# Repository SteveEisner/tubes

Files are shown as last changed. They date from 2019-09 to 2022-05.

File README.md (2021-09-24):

# tubes
These portable LED light poles make pretty lights for a dance party - and better yet:

They're **portable**! Convenient tripod bases keep them standing at attention, and a 10Ah USB battery (like the one you charge your phone with) will power them for about 8 hours.

They're **versatile**! You can deploy them in a [wide open space at Burning Man](https://youtu.be/UtXL0ScNUoE), in a [private event space](https://youtu.be/B6OBde7zRN4), or right next to each other [in your living room](https://youtu.be/UmiRBCOAMBg).  (Click into these links for videos of them in action.)

They're **coordinated**! If you put them next to each other, they sync using near-field radio. And they'll even daisy-chain, meaning the furthest ones can be really far apart as long as there are some in the middle to relay the signal.

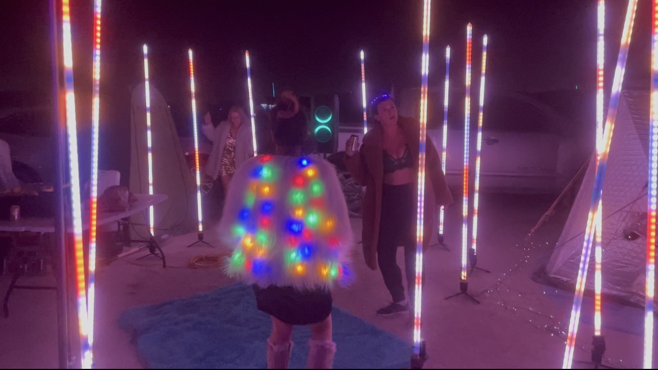
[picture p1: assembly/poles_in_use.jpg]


They're **sturdy**! I built 20 of them and deployed them at parties in all kinds of weather, from hot & dusty windstorms to torrential rain. They've been tossed in a truck, carried around as totems, knocked or blown over, and almost all of 'em are still working.  Just don't let people use them like light sabers (lesson learned.)

They're also **in progress** with lots of things that could be improved.  But for now:

* they play patterns from an expanding set of "genetically-driven" combinations
* they stay in sync or deliberately drift from each other in pleasing ways
* they operate internally at a certain BPM - allowing them to sync to music

### How do they work?

Each light tube is running custom software on a Teensy LC (Arduino-compatible) microcontroller. The software is running a generative light program that has a simple "DNA" specifying its pattern, color, effects overlay, offset, and so on.

The patterns run on a clock that's synced to a specific BPM and counts out the 4/4 rhythm of most dance music, so they morph and change on individual beats, measures, and phrases. After several beat phrases pass, a pole's DNA is mutated a little, which can cause it to change color, or adopt a new pattern, etc.

An on-board NRF radio lets a light pole broadcast its DNA and clock timer; when others hear the signal, they can choose to follow along by updating their own pattern DNA to match it. The method of coordination is pretty simple right now: each pole has an 8-bit ID, and lower-ID poles obey higher-ID poles.

If they're all close enough, they'll soon start doing the same thing as a group and keeping their clock timers in sync. In case they're not close enough, poles also re-broadcast all the signals they receive and obey. This lets them pass along a signal through the group until all of them have found it.

Some randomness and chaos is intentional. Radio isn't 100% reliable, so they sometimes fall out of contact and then re-connect. And in some cases, the poles will deliberately offset their own clock a bit so that they are clearly doing the same thing but not exactly at the same time. Each tube is actually running several copies of the software and smoothly "cross-fading" between them, to avoid any jarring transitions.

### Want your own?

They're not for sale, but check out the build instructions in [this directory](assembly), complete with a parts list & assembly instructions. I'd love it if you build your own!

### Credits

The form factor was inspired by [Mark Lottor's Hexatron](http://www.3waylabs.com/projects/hex/). The color schemes were inspired by [the work of Christopher Schardt](https://americanart.si.edu/exhibitions/burning-man/online/christopher-schardt) and many were found on [cpt-city](http://soliton.vm.bytemark.co.uk/pub/cpt-city/).  The code was written using [FastLED](http://fastled.io/) and most patterns are evolved versions of FastLED examples.  It's based on [Chuck Sommerville's led-swarm](https://github.com/chucks13/LED-swarm), and still follows its [theory](https://github.com/chucks13/LED-swarm/blob/master/theory.txt) for radio connection. I used [Paul Stoffregen's WS2812Serial](https://github.com/PaulStoffregen/WS2812Serial) for smooth animation, and of course [his Teensy CPU](https://www.pjrc.com/teensy/teensyLC.html) made the whole thing possible. Standing on the shoulders of these giants let me create these in about a month, in time to debut at Burning Man 2019 and appear at many parties since!

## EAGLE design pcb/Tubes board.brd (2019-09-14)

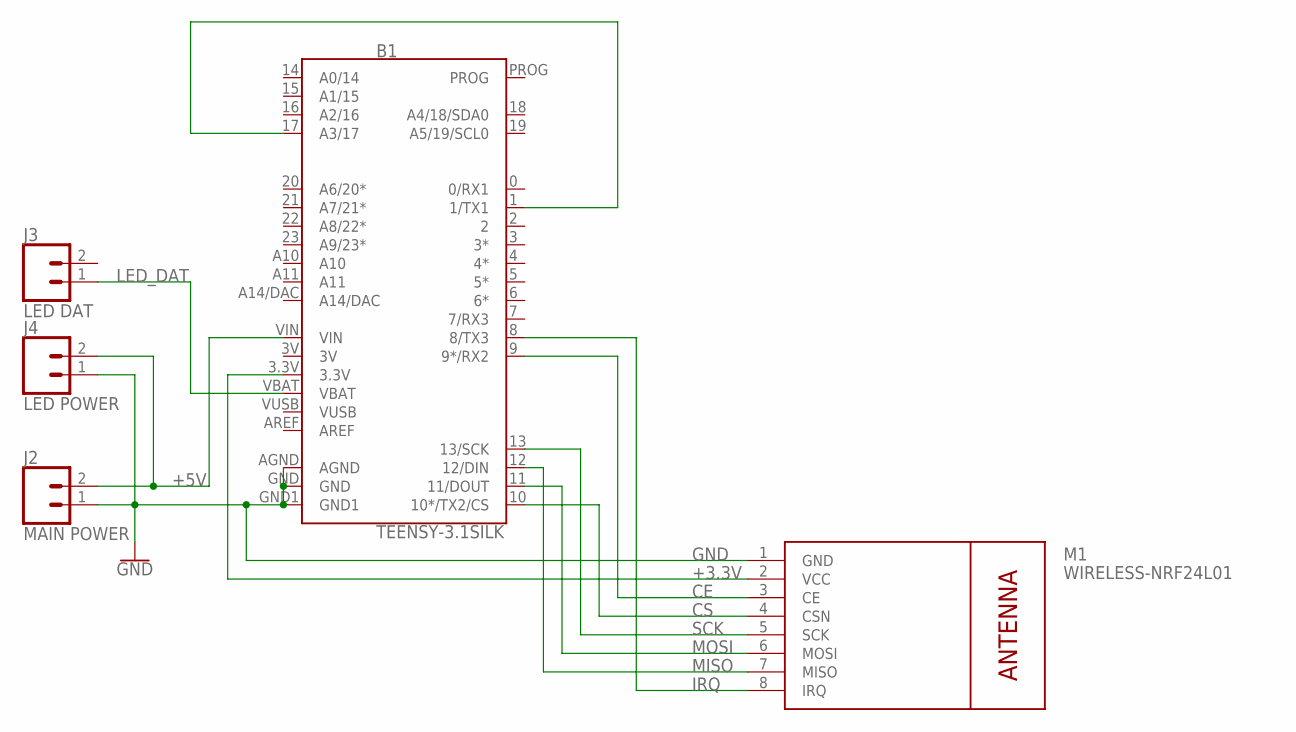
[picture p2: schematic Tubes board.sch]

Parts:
B1: TEENSY-3.1SILK; TEENSY-3.1
J2: MAIN POWER; SCREWTERMINAL-5MM-2
J3: LED DAT; SCREWTERMINAL-5MM-2
J4: LED POWER; SCREWTERMINAL-5MM-2
M1: WIRELESS-NRF24L01

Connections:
3V: B1.3V
+3.3V: B1.3.3V, M1.2 (VCC)
+5V: B1.VIN, J2.2, J4.2
CE: B1.9 (9*/RX2), M1.3 (CE)
CS: B1.10 (10*/TX2/CS), M1.4 (CSN)
DAT: B1.1 (1/TX1), B1.17 (A3/17)
GND: B1.AGND, B1.GND, B1.GND1, J2.1, J4.1, M1.1 (GND)
IRQ: B1.8 (8/TX3), M1.8 (IRQ)
LED_DAT: B1.VBAT, J3.1
MISO: B1.12 (12/DIN), M1.7 (MISO)
MOSI: B1.11 (11/DOUT), M1.6 (MOSI)
SCK: B1.13 (13/SCK), M1.5 (SCK)
VUSB: B1.VUSB

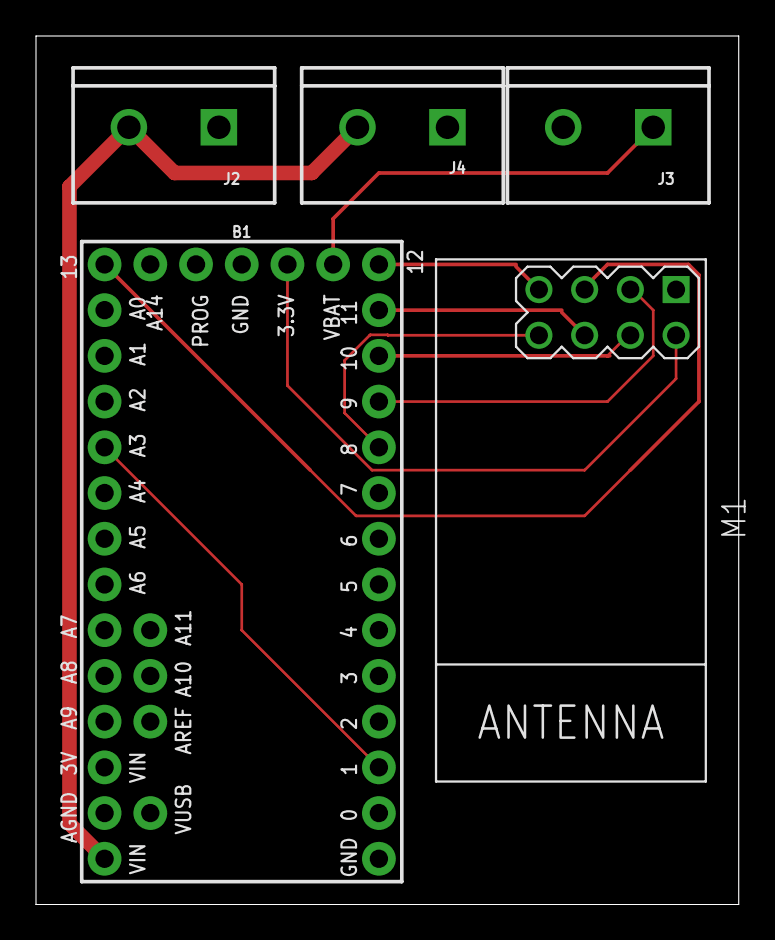
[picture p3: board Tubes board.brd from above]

Board: 2 copper layers, 39.0 x 48.2 mm, 5 parts (0 on the bottom side), 11 nets.

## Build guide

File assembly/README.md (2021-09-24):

# Assembly instructions
How to build your own light tubes.

Quick list of the parts involved:

* A custom PCB (printing instructions & parts are included below.)
* A [specimen cup / paint sample cup](https://www.amazon.com/gp/product/B07RYRF67N) that serves as the housing for the electronics
* A [camera tripod](https://www.amazon.com/gp/product/B072JW7PWX) that acts as the legs
* A [tripod adapter plate](https://www.amazon.com/gp/product/B00H6P57O6), used to strengthen the cup bottom.
* A [flanged nut](https://www.amazon.com/gp/product/B07MJVXWPR) that holds the base together
* The LED light tube itself
* A [shower bar flange](https://www.amazon.com/gp/product/B07K6D7D4F) that holds the light tube in place
* 3 bolts/nut pairs that mount the flange on the top of the cup
* A screw and washer that holds the LED bar against the cup top
* [Mounting foam](https://www.amazon.com/gp/product/B07NYR181P) to secure the PCB
* (Optional) Some [weighted bases](https://www.amazon.com/gp/product/B00PCS196E) that you can slip the tubes into

## The electronics

Eagle files for printing your own PCB are in the [pcb](../pcb) directory.  I used [jlcpcb.com](jlcpcb.com) to print them - fast and cheap! It's incredible that you can have PCBs from Hong Kong at our doorstep within a few days.

The tubes are "meteor lights" like [these ones](https://www.aliexpress.com/item/32678345729.html) but use the frosted plastic like [these ones](https://www.aliexpress.com/item/32977080489.html ) (note that this link is 12V LEDs, don't get those!). Ray Wu's store is universally trusted by LED artists and they do custom orders - they made me some **frosted 2m 5V 30/m SK6812s**. The great thing about these lights is that they're double-sided, for much better 360-degree view of the lights. Each "LED" in the strip is actually a front-and-back pair.

If you want to change the LEDs, for instance to use a different chipset or more LEDS per meter, it'll mostly scale to any size, but you'll need to make small updates the source. You also risk increasing the power consumption.

The code is written for a [Teensy LC](https://www.pjrc.com/teensy/teensyLC.html) microprocessor. It's a cheap, powerful CPU with some nice features for LED applications. You'll need the [Arduino](https://www.arduino.cc/) development environment to flash the code, and I recommend [VSCode](https://code.visualstudio.com/) + [PlatformIO](https://platformio.org/) for editing.

The PCB also has holes ready to accept an NRF radio. I used the ones [without an antenna](https://www.amazon.com/gp/product/B00O9O868G) in each pole. I suppose it could be redesigned around [having an antenna](https://www.amazon.com/gp/product/B07PBBC4H9) although that'll change the form factor a lot. I did use an antenna for the hand-held controller I built - see pics at end.

Finally, each PCB uses 3 [screw terminals](https://www.amazon.com/gp/product/B01MT4LC0F/) for 5v power and data connections.

There are a few improvements I'll make for future versions:

* For USB power, I cut up the USB cords that came free with the batteries I bought. But they're a little short & hard to work with when assembling the base. I'd recommend using longer ones (up to a foot long versus these 4" ones.)
* Oops. I'm going to have to fix the fact that I missed a useful/necessary wire from pin 1 to pin 17 of the Teensy. If you use these boards **you'll need to add a jumper wire** like I did, sorry! :)

## The base

The finished base will look like this:
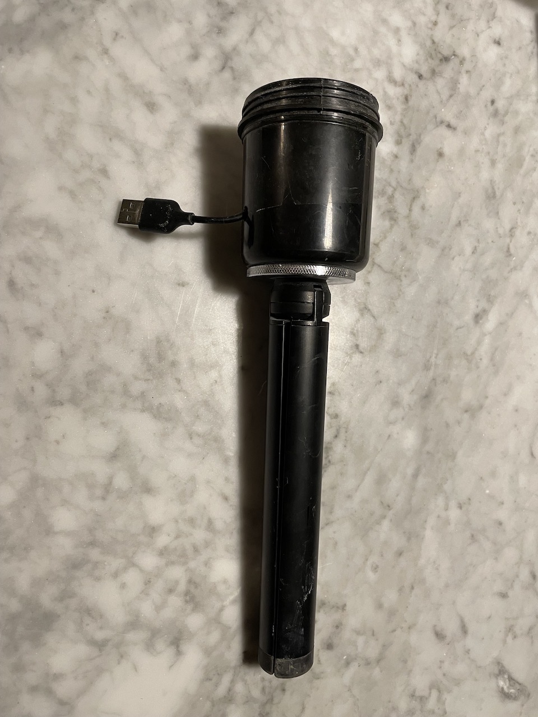
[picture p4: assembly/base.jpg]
base

The tripod is screwed into an adapter plate that provides some stability. That adapter is screwed through a hole in the bottom of the cup, and locked in with a nut on the inside.
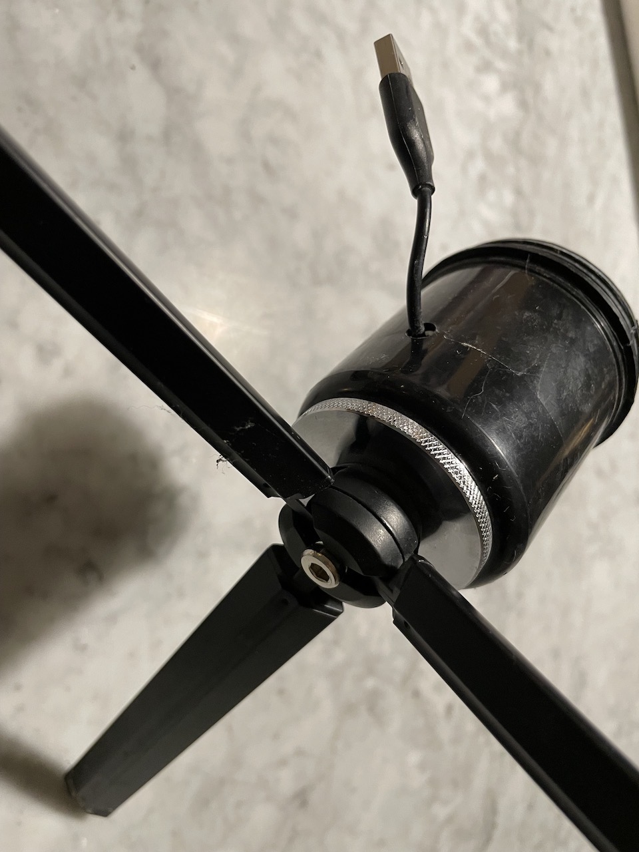
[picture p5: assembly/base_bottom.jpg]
base bottom


Looking down into the cup, you can see the flanged nut that holds it together:
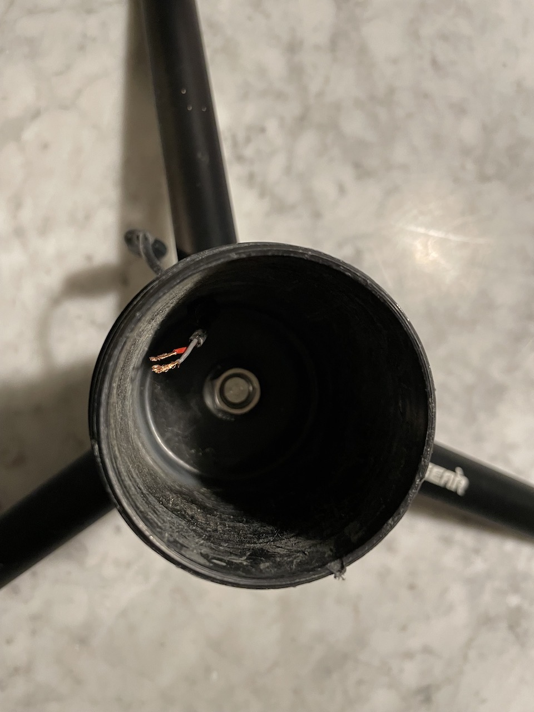
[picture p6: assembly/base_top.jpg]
base from top


Some things I learned while building the base:

* The plastic base of the cup isn't strong enough by itself. It needs to sit on the metal adapter or else the cup will flex/deform and the whole thing will fall over.
* There are multiple kinds of tripods out there. Make sure to get the one that have the updated center screw because the older ones get loose/floppy very quickly.  You'll see mention of this in the seller's notes - they talk about a "version 2" or "updated sturdy screw".  [The Pergear](https://www.amazon.com/dp/B072JW7PWX/ref=emc_b_5_t) tripods I used have the updated bolt, [these Zeadio](https://www.amazon.com/Zeadio-Desktop-Tabletop-Stabilizer-Cameras/dp/B07GST1C2Z) ones don't.

## The tube
The finished tube will look like this:
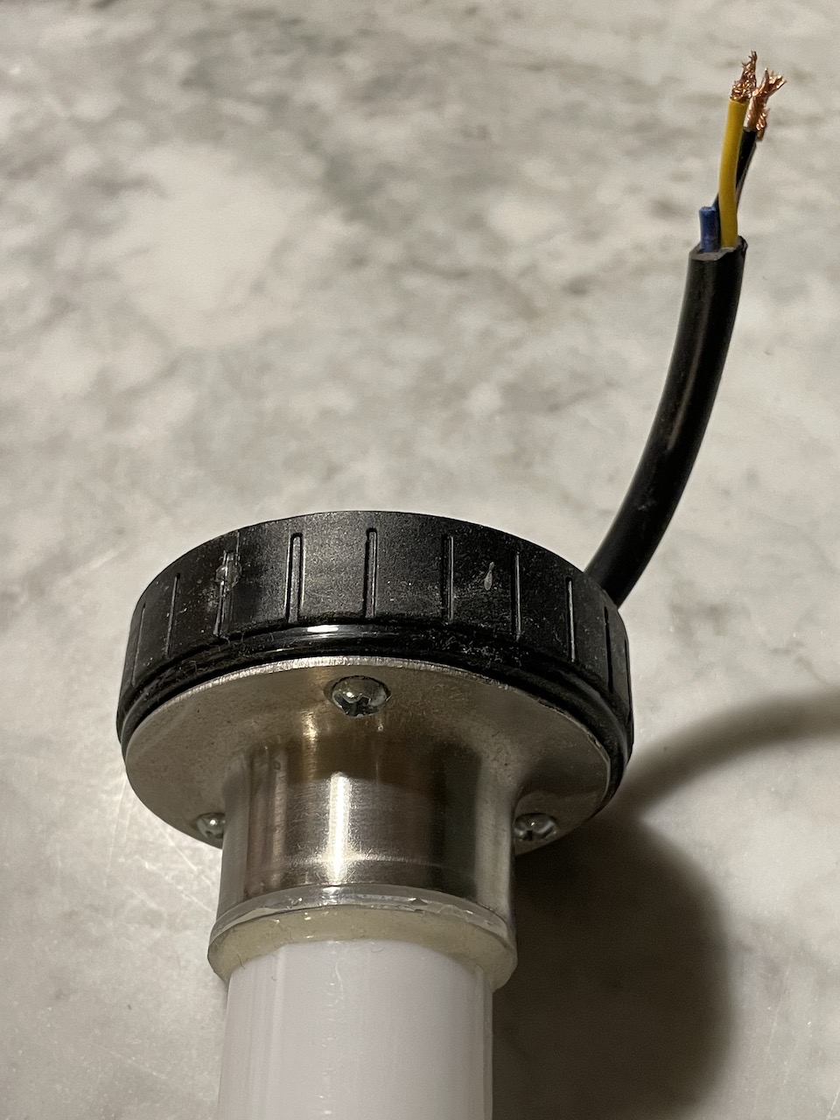
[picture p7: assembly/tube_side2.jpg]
tube from side

They're mounted on the top of the cup, with a flange to hold them in place.

The light tubes are pretty bare when they arrive - no easy mechanism for mounting. I found that I could give them strength by screwing into them from the bottom, but that required a special mounting plate:
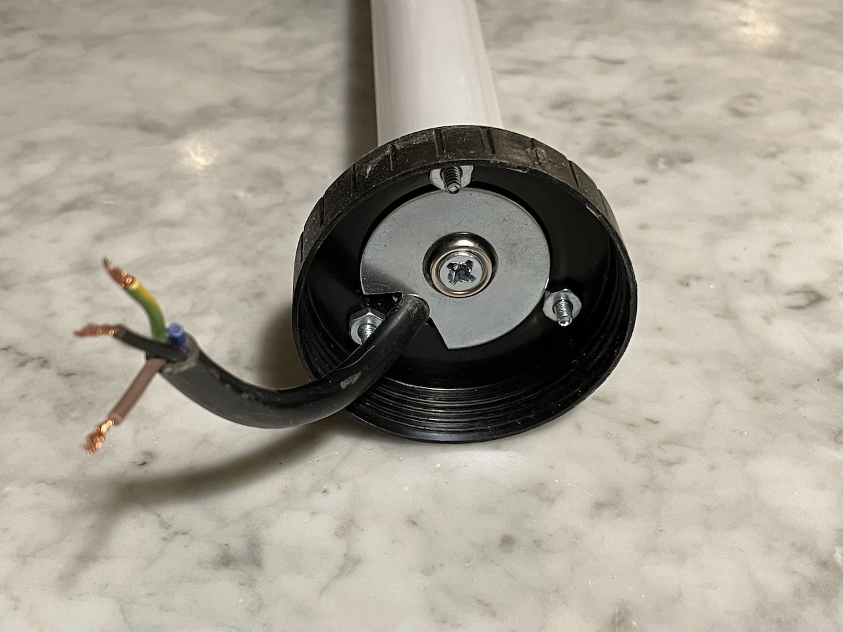
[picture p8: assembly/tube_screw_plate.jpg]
tube plate view


The plate is just a wide washer. I used a drill press to make a hole for the LED strip connector wires, then opened it up a bit with a band saw. You might not need to do that, but it made it easier to get the wires through.

A screw goes up through the washer into the plastic of the tube. It wouldn't be strong enough by itself (the plastic would crack with any pressure on the tube) so the flange on the other side holds it in place. Then the flange can be screwed in from the other side.

Some advice:
* Pre-drill the holes in the cup top. Each will have four holes: three small ones for the flange's screws and one large center one. The center one has to be pretty big to accommodate the wires - I mader mine about an inch wide. The washer/screw combo is clamping the tube to the cup top, so make sure there's enough of the top left to give it strength.
* Also pre-drill a hole into the tube, to prevent the plastic from cracking under strain when you screw into it.
* Between the width of the flat washer and the nuts that hold the flange on, it's pretty tight for space. In my case the nuts just barely fit around the outside of the washer, so screw those 3 in first, and then do the center washer. As a side effect this also keeps the nuts from coming loose, because the washer is keeping them from turning.

## The guts
With the tube and base ready, it's time to fill up the specimen cup. With a PCB!

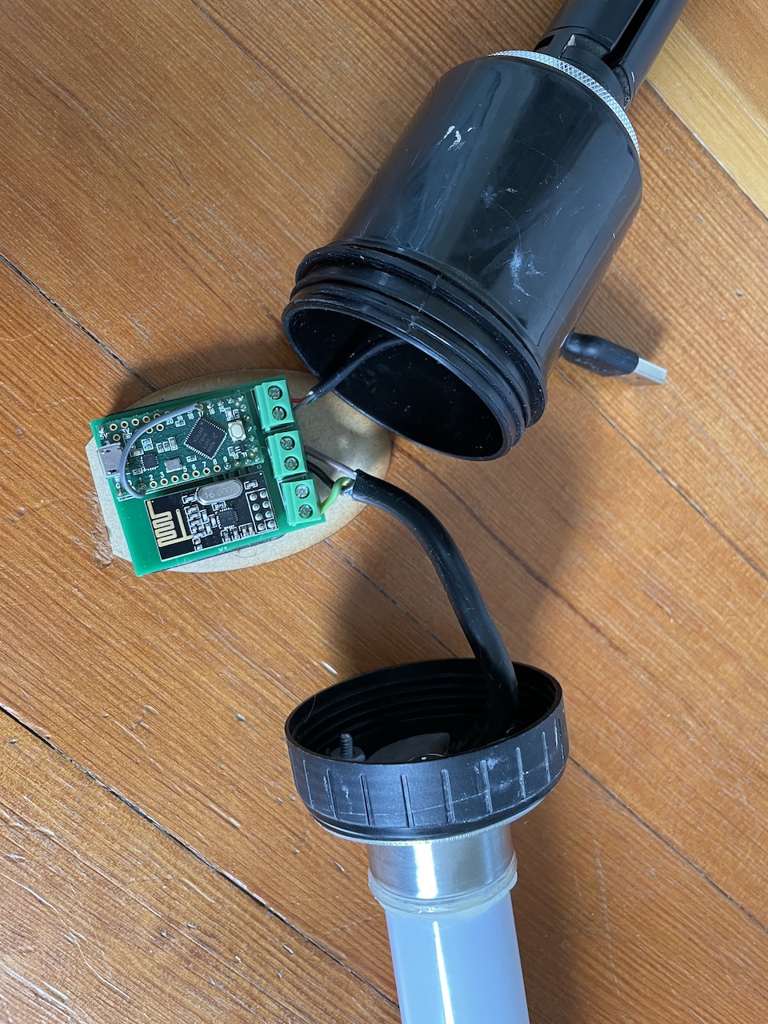
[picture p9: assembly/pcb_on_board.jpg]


My friend laser cut me some elliptical wooden discs to mount the PCBs on:

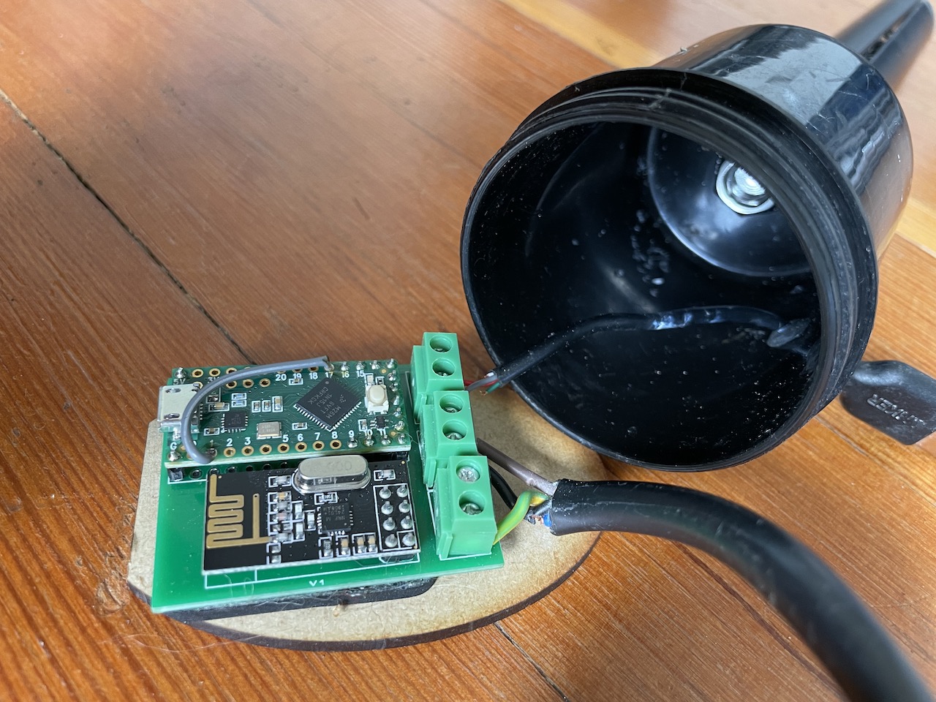
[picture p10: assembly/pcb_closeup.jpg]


They provide some stability to keep the PCB from bouncing around inside the cup. But you could use anything to mount them. The important thing is to not let the PCBs touch the other metal in the cup - the nut on the bottom or the washer & fasteners on the top.

I used double-sided mounting foam to stick the PCB to the wood.  If you don't want to laser cut the wood, maybe you can use the same stuff to make some non-conductive circles and cover the nut and the washer instead.

Lessons learned:

* The cup top screws on to the cup bottom. When you do this, you're going to twist up the wires that are attached to the PCB unless it can freely rotate inside the cup, and even then they'll probably have some twist on them. Make sure the ends of the wires are long enough that they don't get pulled out of the screw terminals.
* The screw top of the cup feels like a weak point, since the top pops off with a little force. Turns out this is a feature not a bug!  By giving the whole thing a bit of a deliberate weak point, it takes pressure off the -true- weak point, which is the glue they used to make the tubes. If you hold everything else solidly together, the tubes themselves will break when a pole falls over!

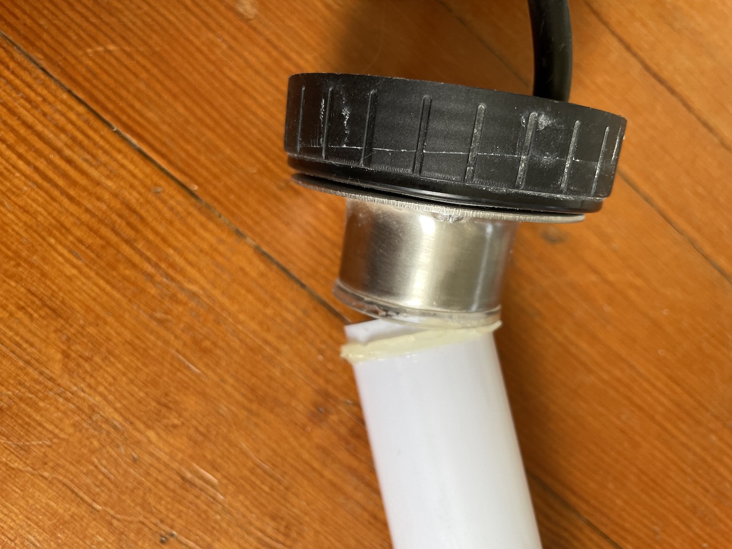
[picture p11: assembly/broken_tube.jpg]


## The controller (optional)

Okay, this part is totally awesome/embarassing.

The day before leaving for Burning Man, I made myself a new toy.

The tubes normally work really well and sync automatically. But their range is limited by the fact that the NRF chips don't have a very big antenna. Occasionally they'll even be right next to each other and still not see each other, in which case one or two might drift apart from the rest.

To achieve perfect coordination, I built a hand-held controller which has the same PCB, but this time I used an [NRF with a big antenna](https://www.amazon.com/gp/product/B07PBBC4H9). It has a special ID that the tubes will always obey, so it acts as a dictator with special powers. It gets them all in sync even if they're 50+ feet apart. And while I was building it, I added some UI to force them to change patterns, colors, and tempo.

It's super useful and also the ugliest thing I've ever built.

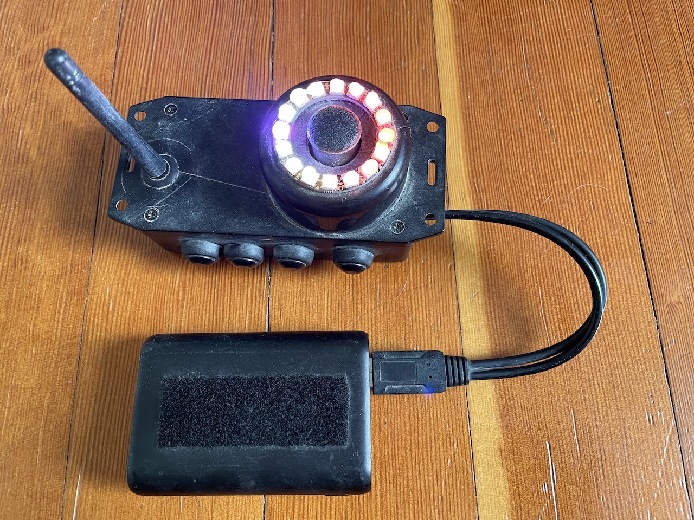
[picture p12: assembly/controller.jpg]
contorller


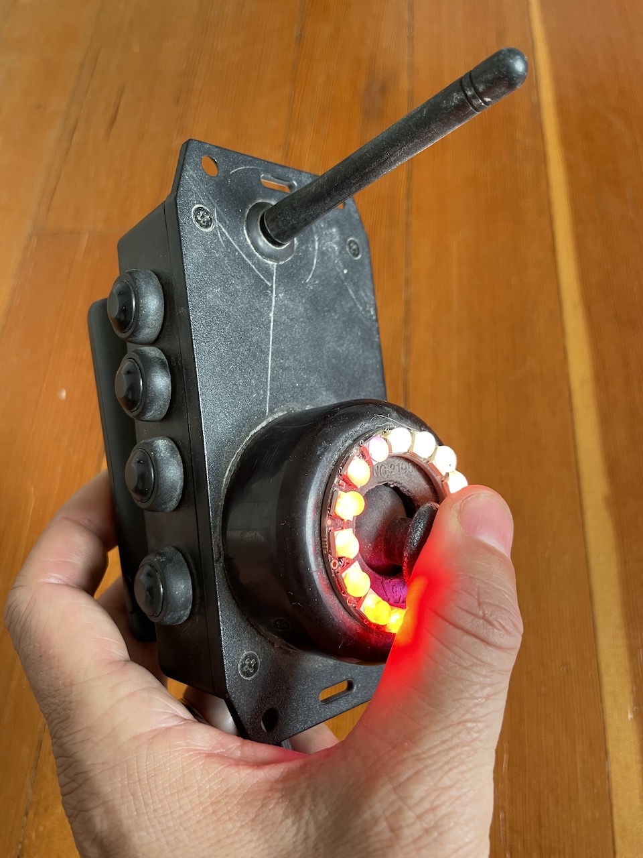
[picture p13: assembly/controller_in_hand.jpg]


I'm not going to do full build instructions for this, but maybe it'll inspire you to make your own. I used parts I had on hand:

* A project box for the body
* The same PCB, now with greater range & a special version of the software
* A rotational joystick like on an Xbox/PS controller
* The bottom of one of the cups as a base for the joystick
* Four pushbuttons
* A 16-LED ring around the joystick
* Hot glue(!) to make diffusers for the LEDs, otherwise they're painfully bright
* Velcro to securely attach a battery under this very ergonomic device
* A [Y-split USB-to-microUSB](https://www.amazon.com/gp/product/B0179OXY9I) cable

The whole thing is such a mess inside:

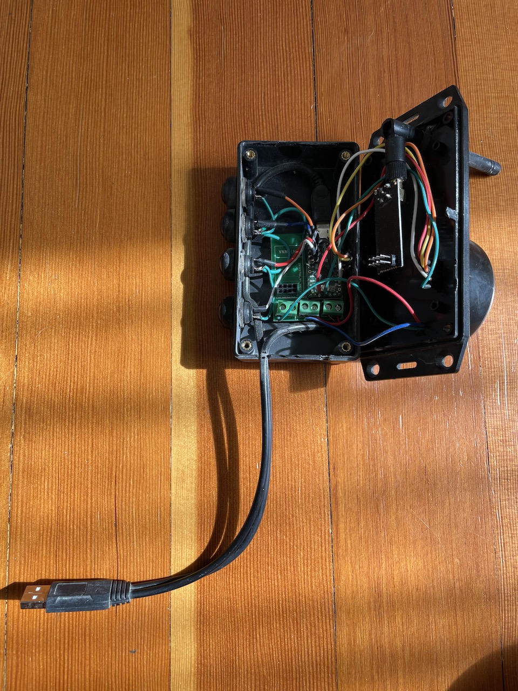
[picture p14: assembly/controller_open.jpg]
controller open


The controller is really just the same light tube PCB and software with a different housing and some inputs. The lights around the joystick show a "thumbnail" (16-LED version) of the pattern it's broadcasting, with a super-imposed white LED marking the current beat.

Besides the extended antenna range, the most useful feature of the controller is setting the BPM of the light poles. One of the buttons lets you tap out a 16-count beat: hold/release, hold/release, hold/release, hold/release, hold/release, hold/release, hold/release, hold/release. The patterns adapt to the new BPM you just tapped out. It's not perfect, so there's beat drift, but it works well enough for now...

[Here's a video showing how it works](https://youtu.be/DNYU71bFSdg). 

After a BPM reset, any nearby light tubes will all be doing the same thing that the controller displays, for instance in this video they're flashing at the start of each beat phrase. The light tubes only do effect changes at the start of a phrase, so things continue to stay in sync until the bpm drifts.

It can also be used to force the tubes into a specific color set, by holding another button and rotating the joystick. Then I still had two unused buttons so I made an intensity control (hold button, use the stick to brighten or dim) and ... some other feature that I forgot. I don't really use those buttons. I'll probably find more useful things for them to do.

Things I learned from this hacked-together experiment:

* In this version of the PCB, I socketed the NRF radio - but the antenna is directly attached to the NRF board, limiting where it can be placed given that the whole thing is mounted on a PCB. I drilled a hole in the enclosure, and used a grommet to hold the antenna tightly in place. It sticks right out from the front of the remote, which isn't pretty!
* I used a split USB cord this time, with one end plugged into the Teensy's microUSB port and one plugged into the screw terminals. Having a data connection means I can flash the controller's software without taking it apart. I'm going to try to do this for the light poles eventually too, but there's not enough room inside the cup for the cable to plug into the Teensy. Maybe there's a right-angle connector that would work.
* The light poles are way cooler when they're in sync with the beat!
* Rotational UI feels great but it's not very precise, so it's still too hard to select specific colors or patterns using the joystick.

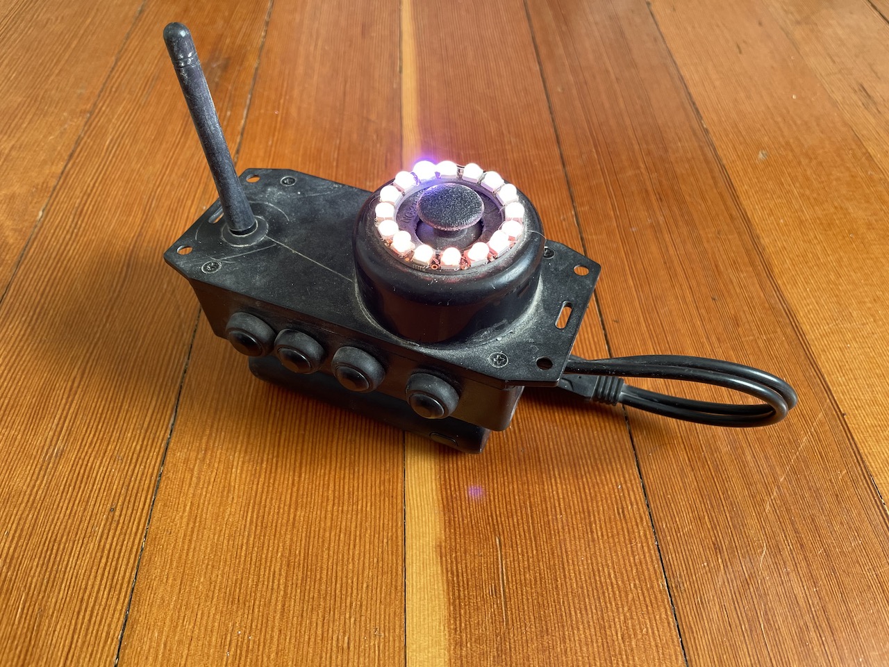
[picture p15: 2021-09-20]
assembly/controller_on_battery.jpg

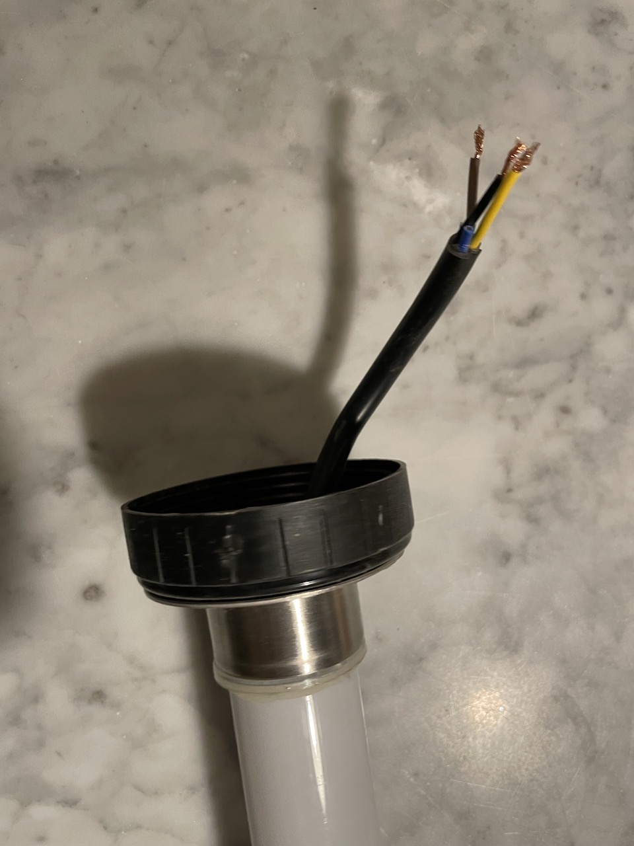
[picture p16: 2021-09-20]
assembly/tube_side.jpg

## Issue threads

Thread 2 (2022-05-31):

Application to non tube structures

intrepidBabyG, 2022-05-31:
Need to apply the same tech to non-tube structures

- Between the layers of corals, could be separate segments or could have the 2 or 3 long lines running through the entire reef
- Frames of the fish tank, are we looking to have well defined lit border for the tank?
- Enhancing sea life - jellyfish, centerpiece  fish
- Outer lower frame of the tank - sand? Need to know it is sand at night
- Inside lighting of the Shell that replaces crow's nest - this should be more ethereal/soft

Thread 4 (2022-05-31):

Small format for clothing

intrepidBabyG, 2022-05-31:
Need to think of a universal length, applicability to clothing, such that we can make it easier and folks can buy and put it together how they want it to make it work on their clothing/bike etc.

- Could they connect multiple together with a certain limit?
- Lower power LED strips, smaller battery pack,  smaller pcb?

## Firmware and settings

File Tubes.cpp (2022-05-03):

#include "platform_config.h"
#include "options.h"

// #define MASTERCONTROL

#define MASTER_PIN 6
#define NUM_LEDS 64

#define USERADIO

#include "beats.h"
#include "virtual_strip.h"

#include "controller.h"
#include "master.h"
#include "radio.h"
#include "debug.h"


BeatController beats;
Radio radio;
PatternController controller(NUM_LEDS, &beats, &radio);
DebugController debug(&controller);
Master *master = NULL;


void randomize(long seed) {
  for (int i = 0; i < seed % 16; i++) {
    randomSeed(random());
  }
  random16_add_entropy( random() );  
}

void setup() {
  delay(2000);
  Serial.begin(115200);
  randomize(analogRead(0));

  pinMode(MASTER_PIN, INPUT_PULLUP);
  if (digitalRead(MASTER_PIN) == LOW) {
    master = new Master(&controller);
    master->setup();
  }

  // Start timing
  globalTimer.setup();
  beats.setup();
  controller.setup(master != NULL);
  debug.setup();
}


void loop()
{
  EVERY_N_MILLISECONDS( 1000 ) {
    randomize(random());
  }

  beats.update(); // ~30us
  controller.update(); // radio: 0-3000us   patterns: 0-3000us   lcd: ~50000us
  debug.update(); // ~25us
  if (master)
    master->update();

  // Draw after everything else is done
  controller.led_strip->update(master != NULL); // ~25us
}

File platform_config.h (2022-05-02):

#pragma once


// ================
// Teensy LC
// ================
#if defined(TEENSYDUINO) && defined(__MKL26Z64__)
#define FASTLED_TEENSYLC
#define FASTLED_ARM
#define FASTLED_ARM_M0_PLUS
#define IS_TEENSY
#define STATIC_MEM PROGMEM
#define __ATMEGA__

// Default to using PROGMEM since TEENSYLC provides it
// even though all it does is ignore it.
#ifndef FASTLED_USE_PROGMEM
#define FASTLED_USE_PROGMEM 1
#endif

// ================
// Teensy 3.X
// ================
#elif defined(TEENSYDUINO) && (defined(__MK20DX128__) || defined(__MK20DX256__) || defined(__MK64FX512__) || defined(__MK66FX1M0__))
#define FASTLED_TEENSY3
#define FASTLED_ARM
#define FASTLED_ARM_M0_PLUS
#define IS_TEENSY
#define __ATMEGA__

// ================
// Teensy 4.X
// ================
#elif defined(TEENSYDUINO) && (defined(__IMXRT1052__) || defined(__IMXRT1062__))
#define FASTLED_TEENSY4
#define IS_TEENSY
#define __TEENSY40__

#endif

// Only try to use PROGMEM on Teensy LCs
#ifndef STATIC_MEM
#define STATIC_MEM
#endif

#define FASTLED_INTERNAL  # turn off pragmas

#ifndef INTERRUPT_THRESHOLD
#define INTERRUPT_THRESHOLD 1
#endif

#define FASTLED_SPI_BYTE_ONLY

// Default to allowing interrupts
#ifndef FASTLED_ALLOW_INTERRUPTS
#define FASTLED_ALLOW_INTERRUPTS 1
#endif

#if FASTLED_ALLOW_INTERRUPTS == 1
#define FASTLED_ACCURATE_CLOCK
#endif

#ifdef IS_TEENSY
#include <WS2812Serial.h>
#define USE_WS2812SERIAL
#endif

#include <FastLED.h>

FASTLED_USING_NAMESPACE

#if defined(FASTLED_VERSION) && (FASTLED_VERSION < 3001000)
#warning "Requires FastLED 3.1 or later"
#endif

uint8_t scaled16to8( uint16_t v, uint16_t lowest=0, uint16_t highest=65535) {
  uint16_t rangewidth = highest - lowest;
  uint16_t scaledbeat = scale16( v, rangewidth );
  uint16_t result = lowest + scaledbeat;
  return result;
}

#include <ustd_array.h>
#include "util.h"

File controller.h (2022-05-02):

#pragma once

#include "beats.h"

#include "pattern.h"
#include "palette.h"
#include "effects.h"
#include "global_state.h"


#include "led_strip.h"
#ifdef USELCD
#include "lcd.h"
#endif
#include "radio.h"

const static uint8_t DEFAULT_MASTER_BRIGHTNESS = 144;

const static CommandId COMMAND_UPDATE = 0x411;
const static CommandId COMMAND_NEXT = 0x321;
const static CommandId COMMAND_RESET = 0x911;
const static CommandId COMMAND_FIREWORK = 0xFFF;
const static CommandId COMMAND_HELLO = 0x000;
const static CommandId COMMAND_OPTIONS = 0x123;
const static CommandId COMMAND_BRIGHTNESS = 0x888;


typedef struct {
  bool debugging;
  uint8_t brightness;
} ControllerOptions;

#define NEXT_PATTERN_TIME 53000
#define NEXT_PALETTE_TIME 27000

#define NUM_VSTRIPS 3

#define DEBOUNCE_TIME 40

class Button {
  public:
    Timer debounceTimer;
    uint8_t pin;
    bool lastPressed = false;

  void setup(uint8_t pin) {
    this->pin = pin;
    pinMode(pin, INPUT_PULLUP);
    this->debounceTimer.start(0);
  }

  bool pressed() {
    if (digitalRead(this->pin) == HIGH) {
      return !this->debounceTimer.ended();
    }

    this->debounceTimer.start(DEBOUNCE_TIME);
    return true;
  }

  bool triggered() {
    // Triggers BOTH low->high AND high->low
    bool p = this->pressed();
    bool lp = this->lastPressed;
    this->lastPressed = p;
    return p != lp;
  }
};

class PatternController : public MessageReceiver {
  public:
    const static int FRAMES_PER_SECOND = 300;  // how often we animate, in frames per second
    const static int REFRESH_PERIOD = 1000 / FRAMES_PER_SECOND;  // how often we animate, in milliseconds

    uint8_t num_leds;
    VirtualStrip *vstrips[NUM_VSTRIPS];
    uint8_t next_vstrip = 0;
    bool isMaster = false;
    
    Timer graphicsTimer;
    Timer updateTimer;
    Timer slaveTimer;

#ifdef USELCD
    Lcd *lcd;
#endif
    LEDs *led_strip;
    BeatController *beats;
    Radio *radio;
    Effects *effects;

    ControllerOptions options;
    char key_buffer[20] = {0};

    Energy energy=LowEnergy;
    TubeState current_state;
    TubeState next_state;

  PatternController(uint8_t num_leds, BeatController *beats, Radio *radio) {
    this->num_leds = num_leds;
#ifdef USELCD
    this->lcd = new Lcd();
#endif
    this->led_strip = new LEDs(num_leds);
    this->beats = beats;
    this->radio = radio;
    this->effects = new Effects();

    for (uint8_t i=0; i < NUM_VSTRIPS; i++) {
#ifdef DOUBLED
      this->vstrips[i] = new VirtualStrip(num_leds * 2 + 1);
#else
      this->vstrips[i] = new VirtualStrip(num_leds);
#endif
    }

  }
  
  void setup(bool isMaster)
  {
    this->isMaster = isMaster;
    this->options.debugging = false;
    this->options.brightness = DEFAULT_MASTER_BRIGHTNESS;

#ifdef USELCD
    this->lcd->setup();
#endif
    this->led_strip->setup();
    Serial.println(F("Graphics: ok"));

    this->set_next_pattern(0);
    this->set_next_palette(0);
    this->set_next_effect(0);
    this->next_state.pattern_phrase = 0;
    this->next_state.palette_phrase = 0;
    this->next_state.effect_phrase = 0;
    Serial.println(F("Patterns: ok"));

    this->radio->setup(this->isMaster);
    this->radio->sendCommand(COMMAND_HELLO);

    this->slaveTimer.start(RADIO_SENDPERIOD * 3); // Assume we're a slave at first, just listen for a master.
    this->updateTimer.start(RADIO_SENDPERIOD); // Ready to send an update as soon as we're able to
  }

  void update()
  {
    this->read_keys();

    // If master has expired, clear masterId
    if (this->radio->masterTubeId && this->slaveTimer.ended()) {
      Serial.println(F("I have no master"));
      this->radio->masterTubeId = 0;
    }

    // Update patterns to the beat
    this->update_beat();

    uint16_t phrase = this->current_state.beat_frame >> 12;
    if (phrase >= this->next_state.pattern_phrase) {
      this->load_pattern(this->next_state);
      this->next_state.pattern_phrase = phrase + this->set_next_pattern(phrase);
    }
    if (phrase >= this->next_state.palette_phrase) {
      this->load_palette(this->next_state);
      this->next_state.palette_phrase = phrase + this->set_next_palette(phrase);
    }
    if (phrase >= this->next_state.effect_phrase) {
      this->load_effect(this->next_state);
      this->next_state.effect_phrase = phrase + this->set_next_effect(phrase);
    }

    // If alone or master, send out updates
    if (!this->radio->masterTubeId and this->updateTimer.ended()) {
      this->send_update();
    }

    this->radio->receiveCommands(this);

    if (this->graphicsTimer.every(REFRESH_PERIOD)) {
      this->updateGraphics();
    }

#ifdef USELCD
    if (this->lcd->active) {
      this->lcd->size(1);
      this->lcd->write(0,56, this->current_state.beat_frame);
      this->lcd->write(80,56, this->x_axis);
      this->lcd->write(100,56, this->y_axis);
      this->lcd->show();

      this->lcd->update();
    }
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

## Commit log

2019-08-10 New buttons; memory optimizations
2019-08-12 Rework master/slave code & prepare for message relaying
    [Tubes.ino, controller.h, radio.h]
2019-08-12 Relayed commands; serial monitoring
2019-08-13 Reorganize timers and create beat fracs
2019-08-14 Revert timer changes and just make patterns change only on a phrase
    [Tubes.ino, controller.h]
2019-08-14 Fix crash due to overallocation of particles; move button logic into controller
    [Tubes.ino, controller.h, particle.h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]
2019-08-16 missing file; spammy error
    [radio.h]
2019-08-16 Rework animations to add more particle effects
    [Tubes.ino, controller.h, fastled_config.h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]
2019-08-22 Fixes for the Burn
    [controller.h, pattern.h]
2019-08-24 move master controls to master.h and fix joystick
    [Tubes.ino, controller.h]
2019-08-29 Button 1 effects
2019-09-14 Check in the master controller; add PCB data
    [Tubes board.brd, Tubes board.sch]
2019-09-14 Add missing wire
    [Tubes board.brd, Tubes board.sch]
2019-09-14 Wire IRQ
    [Tubes board.brd, Tubes board.sch]
2021-09-20 Add assembly instructions
2021-09-21 Update home page and assembly instructions
2022-05-02 Allow compilation on Teensy 3.X, 4.X, LC
2022-05-02 got it compiling for ESP32 (by turning off radio)
2022-05-03 Re-enable NRF radio for ESP32

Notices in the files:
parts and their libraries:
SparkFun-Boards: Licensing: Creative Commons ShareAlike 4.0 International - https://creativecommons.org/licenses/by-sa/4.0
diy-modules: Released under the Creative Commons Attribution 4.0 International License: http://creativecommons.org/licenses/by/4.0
